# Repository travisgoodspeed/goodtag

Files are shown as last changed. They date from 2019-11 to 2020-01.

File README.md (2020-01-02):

# GoodTag

Howdy y'all!

For a long while I've been interested in the RF430FRL152H, which is a
passive RFID tag for 13.56 MHz built around an MSP430 microcontroller.
As few open source examples were available, I found myself first
building a development kit

In this repository, and its
[wiki](https://github.com/travisgoodspeed/goodtag/wiki), you will find
examples and documentation for programming this fine chip, as well as
CAD for hardware boards that use the chip.  This should help you build
your own NFC Type V (ISO 15693) sensor tags, or to emulate existing ones.

This project cannot implement ISO 7816 or ISO 14443 interfaces of
older NFC tags.  For that, you probably need a board designed around
the LPC8N04 or some other microcontroller.

It has partial support for the RF430TAL152H chip found in some medical
devices, written as part of a research project with Axelle Apvrille,
which we presented as [The Inner Guts of a Connected Glucose Sensor
for
Diabetes](https://github.com/cryptax/talks/blob/master/BlackAlps-2019/glucose-blackalps2019.pdf)
at BlackAlps 2019.

73 from Yverdon les Bains,

--Travis Goodspeed

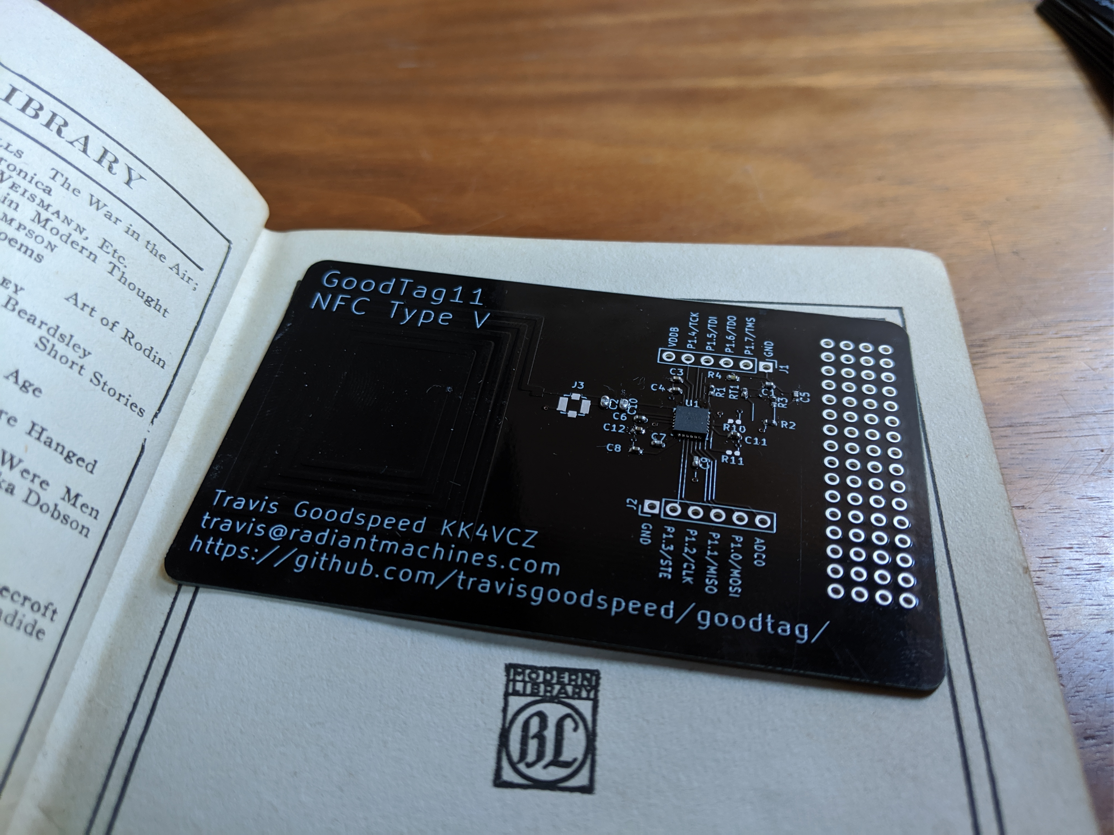
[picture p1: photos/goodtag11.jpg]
GoodTag11 PCB


## Getting Started

See the
[GettingStarted](https://github.com/travisgoodspeed/goodtag/wiki/GettingStarted)
page of the wiki for details on how to begin.  You will need an
assembled board, a Linux shell account, and a recent Android phone,
such as the Pixel 3.

## Toolchain

The C examples in this project *must* be compiled with TI's branch of
[GCC for
MSP430](http://software-dl.ti.com/msp430/msp430_public_sw/mcu/msp430/MSPGCC/latest/index_FDS.html).
We sadly cannot be compatible with the GCC4 branch shipped with Debian
because the function calling conventions are incompatible with the
mask ROM.  You will need both the toolchain and its support files.

See my [GoodV](https://github.com/travisgoodspeed/GoodV) project for
an example Android app that communicates with the chip over NfcV.  It
can write firmware to the tags in the TI-TXT format, as well as dump
their existing contents.

For convenient programming from Linux, the [GreatFET
Hydrangea](https://github.com/travisgoodspeed/hydrangea/) board ought
to be handy.  We'll tie it into the `Makefile` once that project is
functional.

## Documentation

An extensive [goodtag
wiki](https://github.com/travisgoodspeed/goodtag/wiki) covers such
nifty topics as the
[RF430FRL152H](https://github.com/travisgoodspeed/goodtag/wiki/RF430FRL152H)
chip, the contents of [its
ROM](https://github.com/travisgoodspeed/goodtag/wiki/ROM), and the use
of its brother, the otherwise undocumented
[RF430TAL152H](https://github.com/travisgoodspeed/goodtag/wiki/RF430TAL152H).

Axelle Apvrille and Travis Goodspeed presented [The Inner Guts of a
Connected Glucose
Sensor](https://github.com/cryptax/talks/blob/master/BlackAlps-2019/glucose-blackalps2019.pdf)
at BlackAlps 2019, describing a medical sensor that uses the
[RF430TAL152H](https://github.com/travisgoodspeed/goodtag/wiki/RF430TAL152H).

## Firmware

In the `firmware/` directory, you will be find a few example projects.
Most of them are designed to compile as patches to the ROM, hooking
NFC commands rather than being called through the `RESET` vector, so
it's important to remember that global and static variables will *not*
be initialized.

You will probably want to start with `hello.c` and then add your own
vendor extension commands.  `gcmemu.c` is an unfinished emulator for
a commercial glucose sensor tag, and `ndef.c` is an NFC business card
in the NDEF format, which can be read by the
[Decode](https://apps.apple.com/us/app/decode-nfc-scanner/id964303354)
app on an iPhone.

Unlike large applications in which multiple modules are linked
together, this project is organized as individually executable modules
that share no code with one another.  This is considered necessary,
given the pitiful amounts of FRAM code memory.

## Shellcode

In the `shellcode/` directory, you will find short examples of code
that can be run ephemerally from SRAM, without permanent changes to
the target.  See the [Shellcode
page](https://github.com/travisgoodspeed/goodtag/wiki/Shellcode) of
the wiki for a more detailed explanation.

## Hardware Designs

For development, I began by using the
[RF430FRL152HEVM](http://www.ti.com/tool/RF430FRL152HEVM) and
[RF430-TMPSNS-EVM](http://www.ti.com/tool/RF430-TMPSNS-EVM) kits from
Texas Instruments.

As these are now in short supply, I've designed the
[GoodTag11](https://github.com/travisgoodspeed/goodtag/wiki/GoodTag11)
in Kicad as my own development kit.  Expect future designs in this
series.

## Related Projects

[GoodV](https://github.com/travisgoodspeed/GoodV) is an Android app
for interacting with RF430FRL152H devices.  You will probably develop
first with JTAG and then use this to flash your code from a handy
phone.

[The GoodTag Wiki](https://github.com/travisgoodspeed/goodtag/wiki)
contains plenty of documentation about the RF430FRL152H and related
chips.

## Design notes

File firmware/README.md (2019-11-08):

Howdy y'all,

Unfortunately, we have *very* little space and are still stubborn
enough to try writing our code in C.  Then to make matters worse, we
have to call back into the manufacturer's ROM, so we have to use GCC7
as distributed by TI; we can't use the more efficient build that comes
with Debian.

So we need to build a bit differently, and many handy features just
won't be available.  No libc, no printf(), etc.

--Travis

## Examples

`ndef.c` contains no code, but demonstrates an NDEF-formatted tag that
is readable from iPhone or Android.

`hello.c` is a basic example of a tag that implements an additional
vendor command (`A3`) for raw reads of memory.  It uses the NFC stack
from the ROM, but does not use its sensor graphing features.

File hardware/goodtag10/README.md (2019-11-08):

Howdy y'all,

The GoodTag10 is my first attempt at an NFC tag emulator, based around
the RF430FRL152H chip.  As the first attempt, it likely has some
errata that I've not yet found.  Sorry about that.

The passive values roughly come from the Texas Instruments reference
design in SLOA247C.  I've brought a few pins out unnecessarily, in
case bodge wires are needed, but they will be more firmly grounded in
future designs.

For the antenna tuning, I don't really know what I'm doing.  Pull
requests are welcome.

--Travis

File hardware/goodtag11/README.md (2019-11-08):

Howdy y'all,

The GoodTag11 is my attempt at an NFC tag emulator, based around the
RF430FRL152H chip.

The passive values roughly come from the Texas Instruments reference
design in SLOA247C.  I've brought a few pins out unnecessarily, in
case bodge wires are needed, but they will be more firmly grounded in
future designs.

Manufacture in 2layers, 0.024" thickness, FR4-TG130, 1oz, Immersion
Silver, BLACK SOLDER MASK, TWO SIDE MASK, WHITE SILK SCREEN, TOP SILK,
Complex Shape, 8.560cm x 5.398cm.

--Travis

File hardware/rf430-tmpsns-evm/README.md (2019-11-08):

Howdy y'all,

The RF430-TMPSNS-EVM is a passive RFID tag from Texas Instruments,
intended as a demo for temperature sensing.  As a target platform,
it's rather nice because it is a self contained board available
pre-assembled for just ten dollars.

In this directory, you will find the design files as distributed by
Texas Instruments.

--Travis

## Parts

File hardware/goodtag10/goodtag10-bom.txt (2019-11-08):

Designator	Package			QTY	Designation		Digikey
U1		RF430FRL152H		1	RF430FRL152		296-42545-1-ND
C1,C5		0402 (1005 metric)	2	22pF			311-1018-1-ND
RT1		0402 (1005 metric)	2	100K Thermistor		490-2404-1-ND
R3		0402 (1005 metric)	2	100K			P100KDECT-ND
R1,R2		0402 (1005 metric)	2	1K			YAG1234CT-ND
C2		0402 (1005 metric)	1	91pF			311-3756-1-ND
R10,R11		0402 (1005 metric)	2	0R			RMCF0402ZT0R00CT-ND
R4		0402 (1005 metric)	1	10K			RR05P10.0KDCT-ND
C3,C4,C8,C12	0402 (1005 metric)	4	100nF			1276-1004-1-ND
C11		0402 (1005 metric)	1	1µF			1276-1235-1-ND
C7,C9		0402 (1005 metric)	2	10nF			311-1014-1-ND
C6		0402 (1005 metric)	1	2.2µF			587-3153-1-ND

Notes:

1) Do not populate the pin headers or the U.FL antenna connector.

2) The sum of C2 and C10 should be roughly 88pF.  I used four 22pF
   caps to verify this, but one 91pF cap on C2 will probably work just
   fine when C10 is not populated.

3) R10 and R11 are listed as zero Ohm, but larger values probably
   wouldn't hurt.  Later revisions might drop one or both of them for
   wire traces.

4) This first revision of the PCB does not support a battery.  Later
   versions might add an optional one.

5) The RF430FRL152 is the most featureful, but in mass production for
   a specific application, you can probably save some money by
   substituting the FRL153 or 154.

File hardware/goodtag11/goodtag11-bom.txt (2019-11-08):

Designator	Package			QTY	Designation		Digikey
U1		RF430FRL152H		1	RF430FRL152		296-42545-1-ND
C1,C5		0402 (1005 metric)	2	22pF			311-1018-1-ND
RT1		0402 (1005 metric)	2	100K Thermistor		490-2404-1-ND
R3		0402 (1005 metric)	2	100K			P100KDECT-ND
R1,R2		0402 (1005 metric)	2	1K			YAG1234CT-ND
C2		0402 (1005 metric)	1	91pF			311-3756-1-ND
R4		0402 (1005 metric)	1	10K			RR05P10.0KDCT-ND
C3,C4,C8,C12	0402 (1005 metric)	4	100nF			1276-1004-1-ND
C11		0402 (1005 metric)	1	1µF			1276-1235-1-ND
C7,C9		0402 (1005 metric)	2	10nF			311-1014-1-ND
C6		0402 (1005 metric)	1	2.2µF			587-3153-1-ND

Notes:

1) Do not populate the pin headers or the U.FL antenna connector.

2) The sum of C2 and C10 should be roughly 88pF.  I used four 22pF
   caps to verify this, but one 91pF cap on C2 will probably work just
   fine when C10 is not populated.  Wildly inaccurate tuning will
   produce a tag that works with some readers, but not others.

3) R10 and R11 were 0 Ohm resistors in the prior revision.  Now, they
   are shorted in the copper layer.  If you need to experiment with
   those pins, cut the trace and fly-wire the 0402 pad.

4) This revision of the PCB does not support a battery.  Later
   versions might add an optional one.

5) The RF430FRL152 is the most featureful, but in mass production for
   a specific application, you can probably save some money by
   substituting the FRL153 or 154.

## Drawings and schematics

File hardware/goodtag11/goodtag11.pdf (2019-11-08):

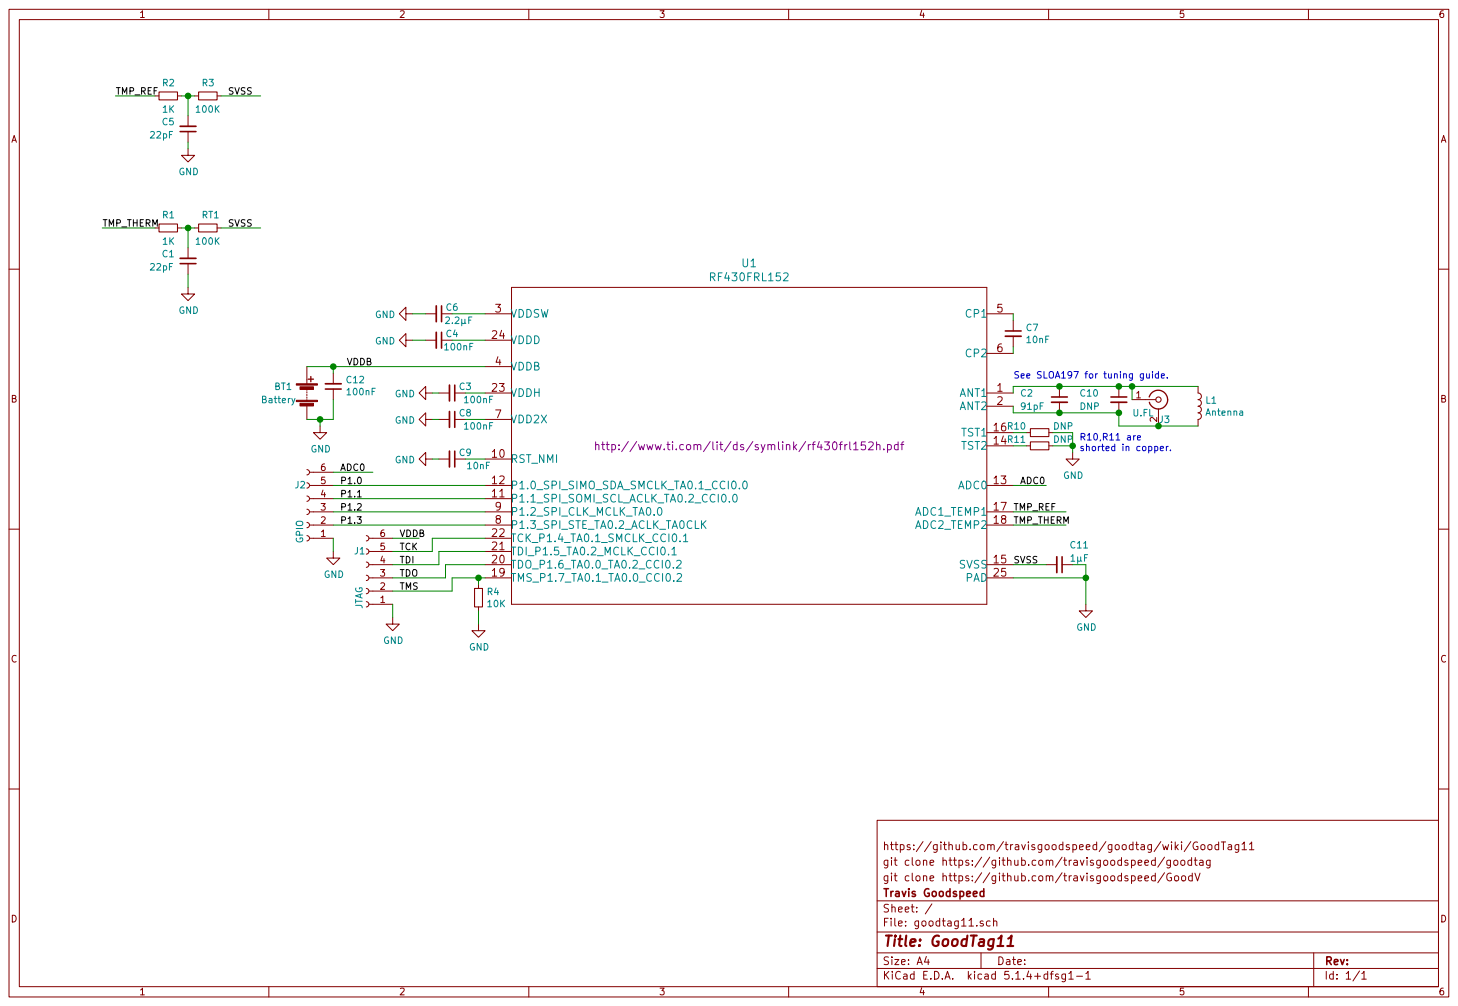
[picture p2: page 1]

http://www.ti.com/lit/ds/symlink/rf430frl152h.pdf C5

See SLOA197 for tuning guide.

https://github.com/travisgoodspeed/goodtag/wiki/GoodTag11 GNDGND

git clone https://github.com/travisgoodspeed/goodtag
git clone https://github.com/travisgoodspeed/GoodV
File: goodtag11.sch Sheet: / Travis Goodspeed

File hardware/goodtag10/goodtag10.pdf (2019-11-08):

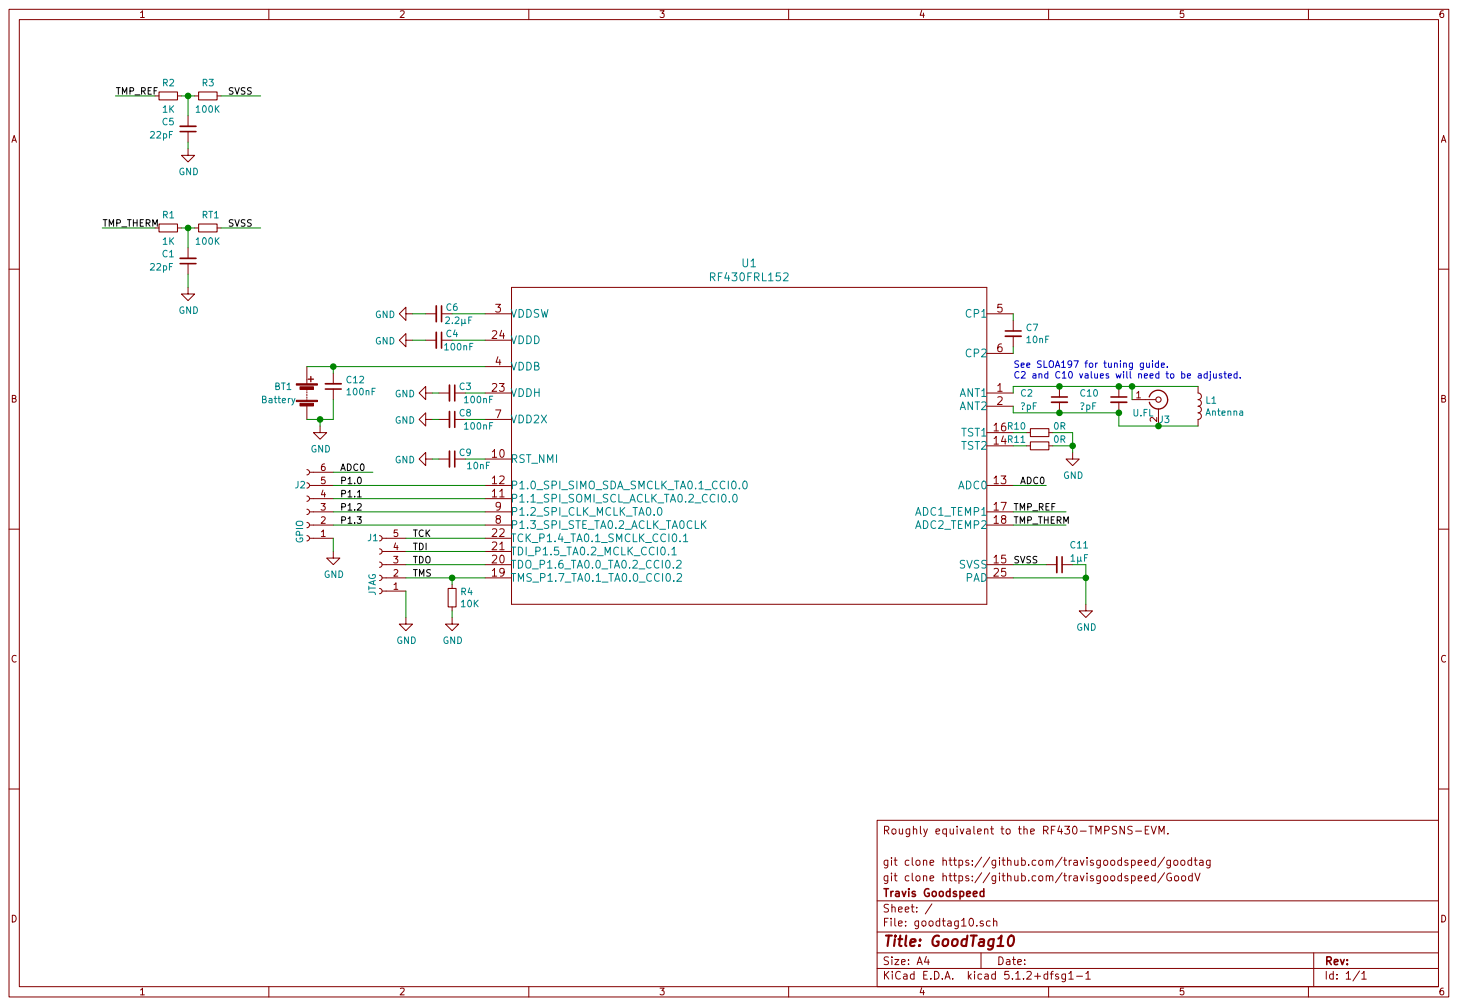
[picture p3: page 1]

See SLOA197 for tuning guide.

C2 and C10 values will need to be adjusted. R4

git clone https://github.com/travisgoodspeed/goodtag
git clone https://github.com/travisgoodspeed/GoodV
File: goodtag10.sch Sheet: / Travis Goodspeed

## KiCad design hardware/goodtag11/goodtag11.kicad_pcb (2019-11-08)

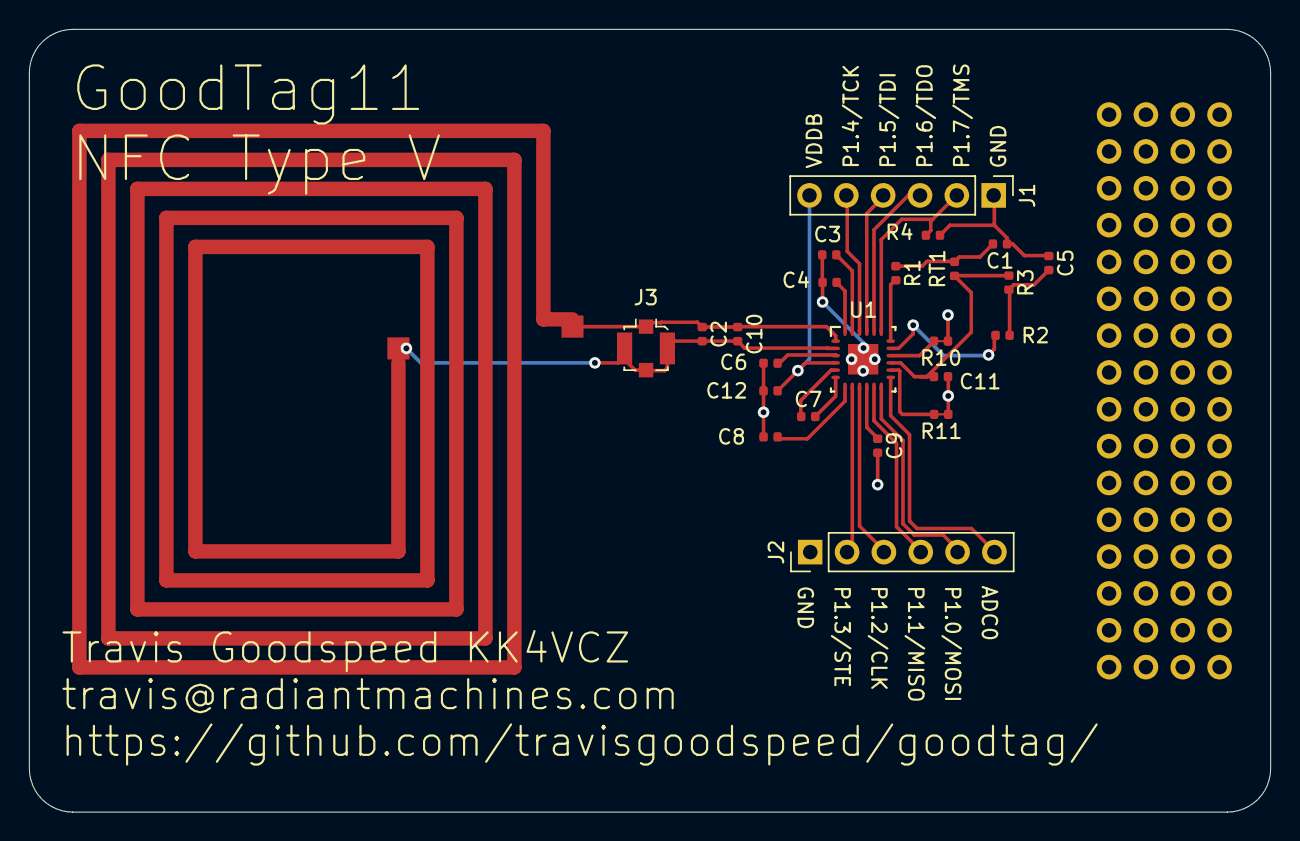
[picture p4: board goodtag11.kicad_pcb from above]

Board: 2 copper layers, 85.6 x 54.0 mm, 32 parts (0 on the bottom side), 27 nets.

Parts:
 : proto1x8
 #2,  #3,  #4,  #5,  #6,  #7,  #8: proto1x8
C1, C5: 22pF; C_0402_1005Metric
C2: 91pF; C_0402_1005Metric
C3, C4, C8, C12: 100nF; C_0402_1005Metric
C6: 2.2µF; C_0402_1005Metric
C7, C9: 10nF; C_0402_1005Metric
C10: DNP; C_0402_1005Metric
C11: 1µF; C_0402_1005Metric
J1: JTAG; PinHeader_1x06_P2.54mm_Vertical
J2: GPIO; PinHeader_1x06_P2.54mm_Vertical
J3: U.FL; U.FL_Molex_MCRF_73412-0110_Vertical
L1: Antenna; GW10ANT
R1, R2: 1K; R_0402_1005Metric
R3: 100K; R_0402_1005Metric
R4: 10K; R_0402_1005Metric
R10, R11: DNP; R_0402_shorted
RT1: 100K; R_0402_1005Metric
U1: RF430FRL152; RF430FRL152H

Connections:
/ADC0: J2.6, U1.13
/P1.0: J2.5, U1.12
/P1.1: J2.4, U1.11
/P1.2: J2.3, U1.9
/P1.3: J2.2, U1.8
/SVSS: C11.2, R3.1, RT1.1, U1.15
/TCK: J1.5, U1.22
/TDI: J1.4, U1.21
/TDO: J1.3, U1.20
/TMP_REF: R2.2, U1.17
/TMP_THERM: R1.2, U1.18
/TMS: J1.2, R4.1, U1.19
/VDDB: C12.2, J1.6, U1.4
GND: C1.1, C3.2, C4.2, C5.1, C6.2, C8.2, C9.2, C11.1, C12.1, J1.1, J2.1, R4.2, R10.1, R11.1, U1.25
unnamed: C1.2, R1.1, RT1.2
unnamed: C3.1, U1.23
unnamed: C4.1, U1.24
unnamed: C5.2, R2.1, R3.2
unnamed: C6.1, U1.3
unnamed: C7.1, U1.5
unnamed: C7.2, U1.6
unnamed: C8.1, U1.7
unnamed: C9.1, U1.10
unnamed: C2.1, C10.1, J3.1, L1.1, U1.1
unnamed: C2.2, C10.2, J3.2, L1.2, U1.2
unnamed: R10.2, U1.16
unnamed: R11.2, U1.14

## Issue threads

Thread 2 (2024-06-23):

License Question

nickpalladino, 2024-06-23:
Hey @travisgoodspeed, I had a few goodtag11 boards made up to evaluate the RF430FRL152H. I also forked GoodV and updated it a bit. Would you have an issue with me putting up my extra boards for sale and publishing GoodV in the Play Store? I didn't see any license information in the repos.

Thanks,
Nick

travisgoodspeed, 2024-06-23:
Forks are welcome, of course.  Please label it as a fork if you've made changes and kindly share a devkit with a student when you get a chance.

Closed 2024-06-23.
